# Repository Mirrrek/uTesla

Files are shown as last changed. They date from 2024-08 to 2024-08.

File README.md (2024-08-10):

# uTesla

uTesla (_microTesla_) is a small in size, but definitely impressive Tesla coil. It's core drive circuitry is inspired by [Tefatronix](https://tefatronix.g6.cz/)'s (a fellow Czech!) SSTC IV. The driver runs on 24V (up to 28V for those feeling adventurous) and is controlled by an ATmega328P microcontroller with an SD card slot.

## Hardware

uTesla consists of three main components:

### The driver board

Schematics for this board are available in the [schematic](https://github.com/Mirrrek/uTesla/tree/main/schematic) folder.

The board is intended to be installed with the components facing down. The other side of the PCB serves as a shield from the electromagnetic radiation produced by the coil.

Additional shielding may be required, such as covering the ATmega328P with copper tape (make sure not to short anything out!) connected to the grounding pads present throughout the board.

### The primary coil

Similarly to Tefatronix's design, a 16 pin ribbon cable connected in a A-24V, 24V-B, A-24V, 24V-B pattern serves as the primary coil.

The primary diameter should be around 2cm larger than the secondary coil.

### The secondary coil

Again, this closely follows Tefatronix's design. The secondary consists of a ~3.5cm diameter PVC pipe with around 500 turns of 0.1mm enameled copper wire wound around it.

The resonance can be maximized using tuning capacitors, so the secondary coil doesn't have to match exactly.

## Software

Software for uTesla is a work in progress.

## Expansion

For simple changes (e.g. adding an LCD screen with some buttons) the board has an IO header with 10 pins available.

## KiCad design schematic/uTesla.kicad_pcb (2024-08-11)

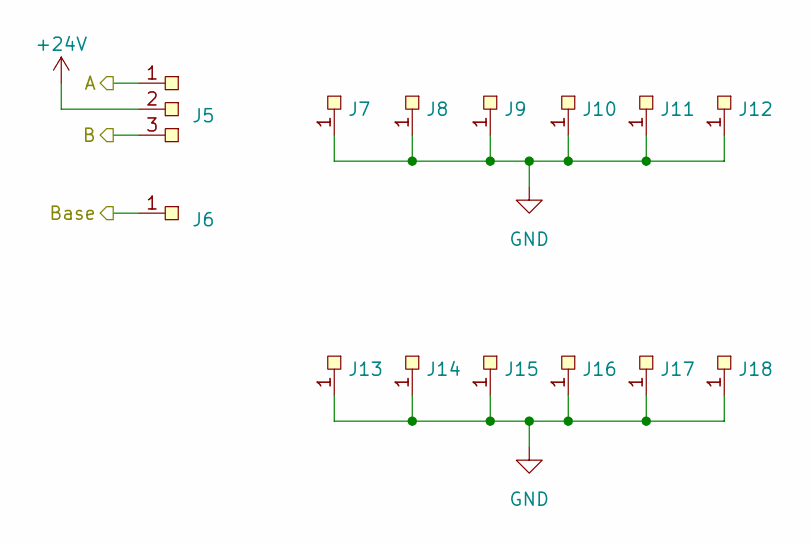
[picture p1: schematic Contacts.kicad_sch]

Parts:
J5: SolderPad-3pin
J6, J7, J8, J9, J10, J11, J12, J13, J14, J15, J16, J17, J18: SolderPad-1pin

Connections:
+24V: J5.2; also elsewhere on the board
/Contacts/A: J5.1; also elsewhere on the board
/Contacts/B: J5.3; also elsewhere on the board
/Contacts/Base: J6.1; also elsewhere on the board
GND: J7.1, J8.1, J9.1, J10.1, J11.1, J12.1, J13.1, J14.1, J15.1, J16.1, J17.1, J18.1; also elsewhere on the board

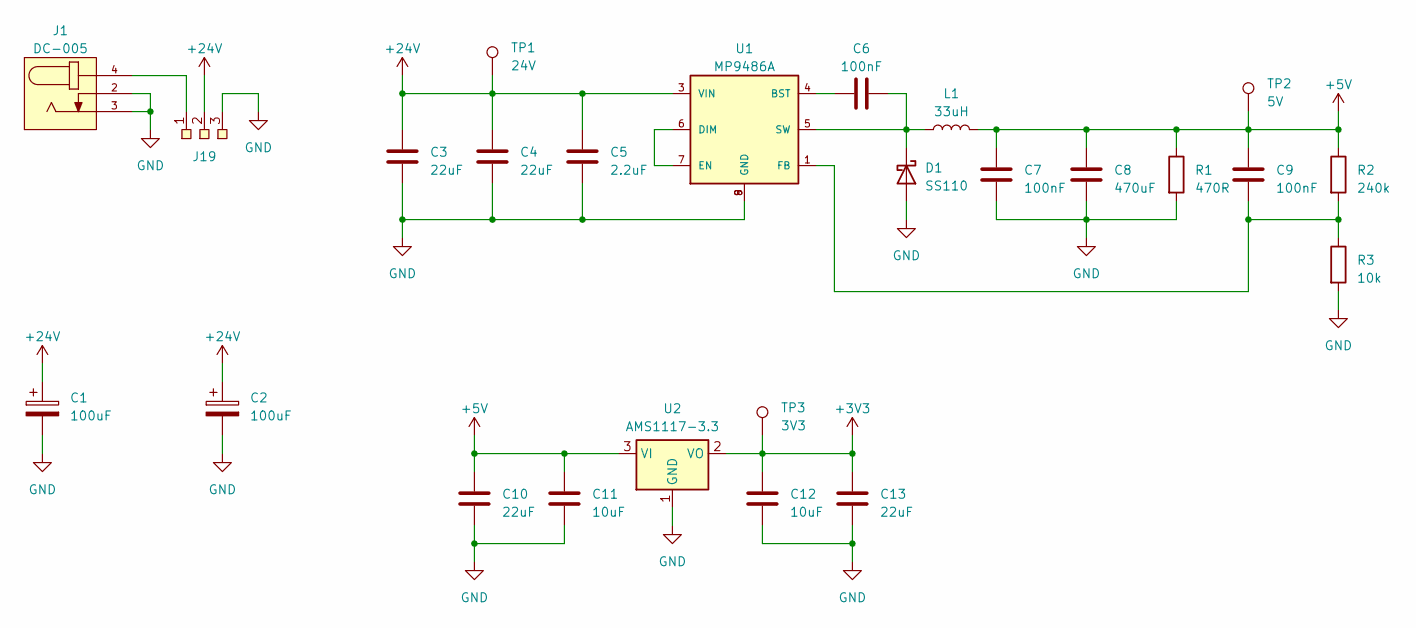
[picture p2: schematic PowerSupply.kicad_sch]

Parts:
C1, C2: 100uF; CP_Radial_D8.0mm_P3.80mm
C3, C4, C10, C13: 22uF; C_0603_1608Metric
C5: 2.2uF; C_0603_1608Metric
C6, C7, C9: 100nF; C_0603_1608Metric
C8: 470uF; C_0603_1608Metric
C11, C12: 10uF; C_0603_1608Metric
D1: SS110; D_SMA
J1: DC-005; NINIGI_DC-005
J19: SolderPad-3pin
L1: 33uH; L_Toroid_Vertical_L26.7mm_W14.0mm_P10.16mm_Pulse_D
R1: 470R; R_0603_1608Metric
R2: 240k; R_0603_1608Metric
R3: 10k; R_0603_1608Metric
TP1: 24V; TestPoint_Pad_D2.0mm
TP2: 5V; TestPoint_Pad_D2.0mm
TP3: 3V3; TestPoint_Pad_D2.0mm
U1: MP9486A; SOIC-8EP
U2: AMS1117-3.3; SOT-223-3_TabPin2

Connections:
+3V3: C12.1, C13.1, TP3.1, U2.2 (VO); also elsewhere on the board
+5V: C7.1, C8.1, C9.1, C10.1, C11.1, L1.2, R1.1, R2.1, TP2.1, U2.3 (VI); also elsewhere on the board
+24V: C1.1, C2.1, C3.1, C4.1, C5.1, J19.2, TP1.1, U1.3 (VIN); also elsewhere on the board
GND: C1.2, C2.2, C3.2, C4.2, C5.2, C7.2, C8.2, C10.2, C11.2, C12.2, C13.2, D1.2 (A), J1.2, J1.3, J19.3, R1.2, R3.2, U1.8 (GND), U1.9 (GND), U2.1 (GND); also elsewhere on the board
unnamed: C6.2, D1.1 (K), L1.1, U1.5 (SW)
unnamed: J1.4, J19.1
unnamed: C6.1, U1.4 (BST)
unnamed: U1.6 (DIM), U1.7 (EN)
unnamed: C9.2, R2.2, R3.1, U1.1 (FB)

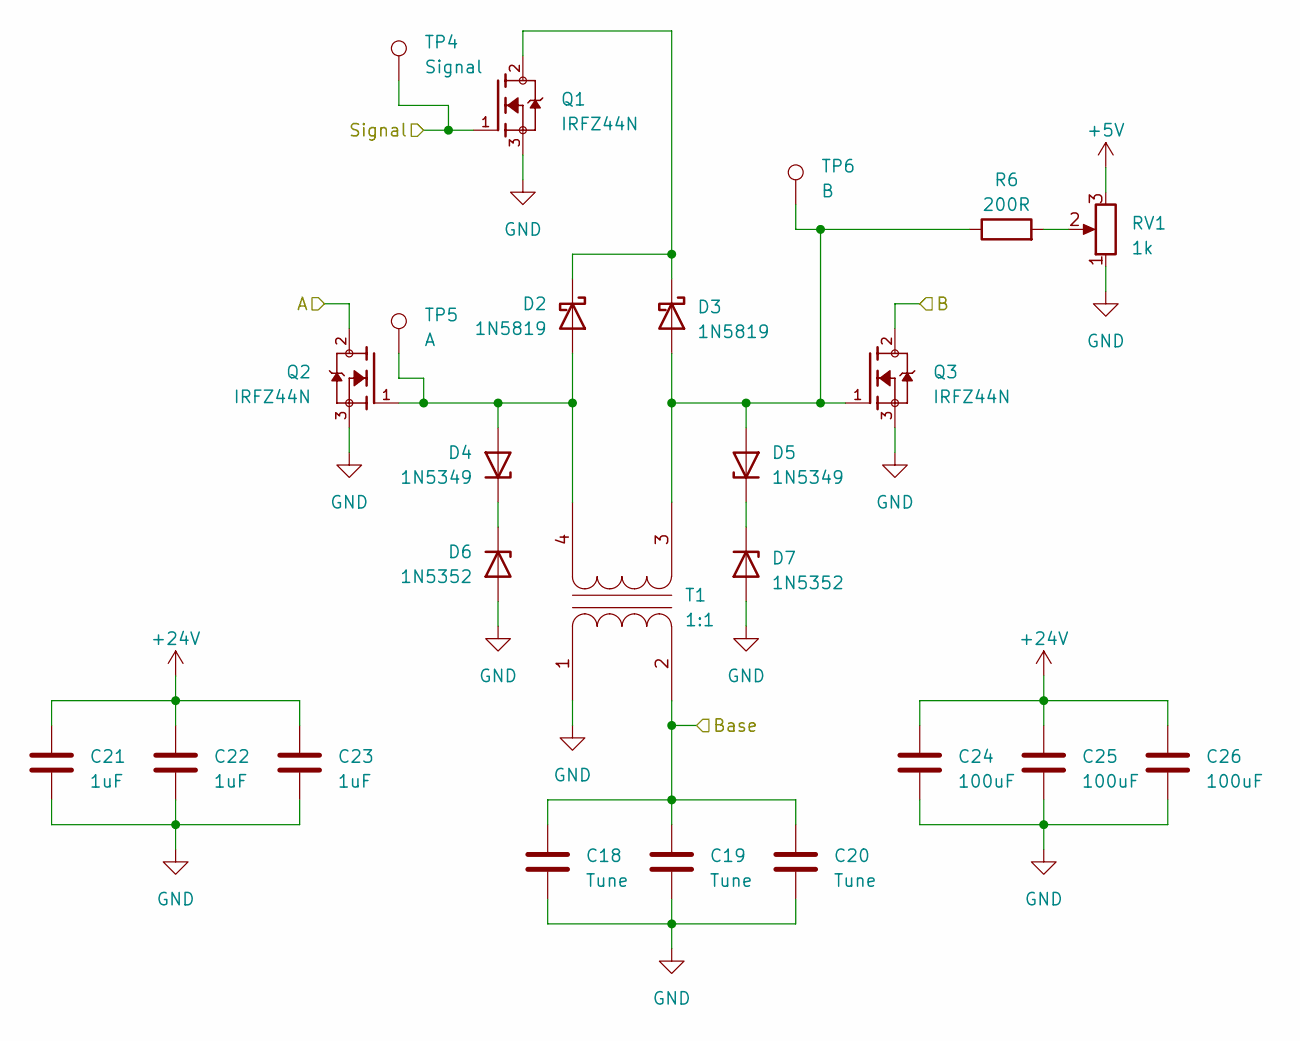
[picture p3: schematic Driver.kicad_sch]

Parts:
C18, C19, C20: Tune; C_0603_1608Metric
C21, C22, C23: 1uF; C_0603_1608Metric
C24, C25, C26: 100uF; CP_Radial_D8.0mm_P3.80mm
D2, D3: 1N5819; D_DO-41_SOD81_P10.16mm_Horizontal
D4, D5: 1N5349; D_DO-41_SOD81_P10.16mm_Horizontal
D6, D7: 1N5352; D_DO-41_SOD81_P10.16mm_Horizontal
Q1, Q2, Q3: IRFZ44N; TO254P1016X419X2286-3; PARTREV 09/21/10
R6: 200R; R_0603_1608Metric
RV1: 1k; Potentiometer_Runtron_RM-065_Vertical
T1: 1:1; Transformer_Toroid_Horizontal_D9.0mm_Amidon-T30
TP4: Signal; TestPoint_Pad_D2.0mm
TP5: A; TestPoint_Pad_D2.0mm
TP6: B; TestPoint_Pad_D2.0mm

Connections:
+5V: RV1.3; also elsewhere on the board
+24V: C21.1, C22.1, C23.1, C24.1, C25.1, C26.1; also elsewhere on the board
/Contacts/A: Q2.2; also elsewhere on the board
/Contacts/B: Q3.2; also elsewhere on the board
/Contacts/Base: C18.1, C19.1, C20.1, T1.2 (AB); also elsewhere on the board
/Driver/Signal: Q1.1, TP4.1; also elsewhere on the board
GND: C18.2, C19.2, C20.2, C21.2, C22.2, C23.2, C24.2, C25.2, C26.2, D6.2 (A), D7.2 (A), Q1.3, Q2.3, Q3.3, RV1.1, T1.1 (AA); also elsewhere on the board
unnamed: D2.2 (A), D4.2 (A), Q2.1, T1.4 (SB), TP5.1
unnamed: D2.1 (K), D3.1 (K), Q1.2
unnamed: D3.2 (A), D5.2 (A), Q3.1, R6.1, T1.3 (SA), TP6.1
unnamed: D4.1 (K), D6.1 (K)
unnamed: D5.1 (K), D7.1 (K)
unnamed: R6.2, RV1.2

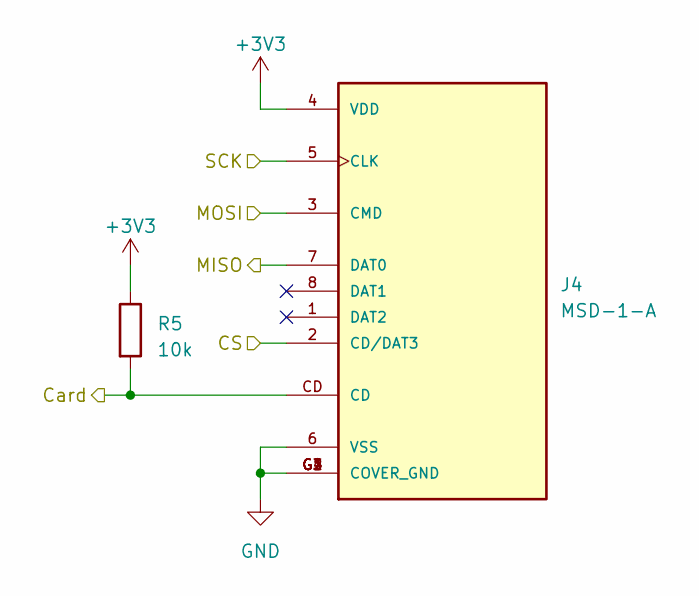
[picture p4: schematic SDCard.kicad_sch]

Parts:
J4: MSD-1-A; CUI_MSD-1-A; PARTREV 1.0
R5: 10k; R_0603_1608Metric

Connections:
+3V3: J4.4 (VDD), R5.1; also elsewhere on the board
/Microcontroller/CS: J4.2 (CD/DAT3); also elsewhere on the board
/Microcontroller/Card: J4.CD, R5.2; also elsewhere on the board
/Microcontroller/MISO: J4.7 (DAT0); also elsewhere on the board
/Microcontroller/MOSI: J4.3 (CMD); also elsewhere on the board
/Microcontroller/SCK: J4.5 (CLK); also elsewhere on the board
GND: J4.6 (VSS), J4.G1 (COVER_GND), J4.G2 (COVER_GND), J4.G3 (COVER_GND), J4.G4 (COVER_GND); also elsewhere on the board

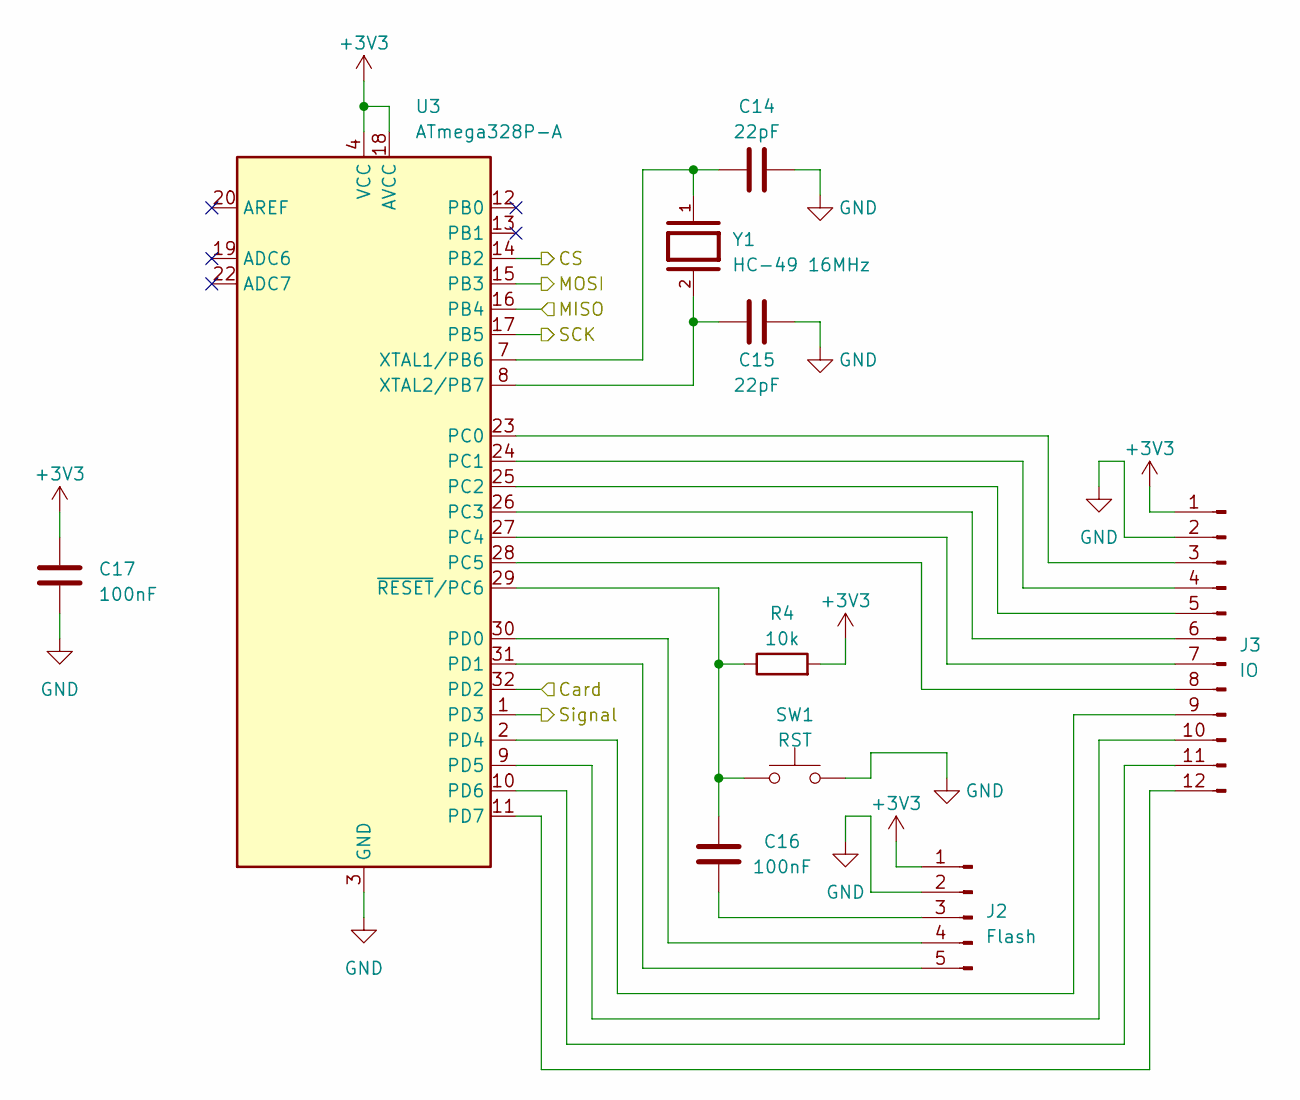
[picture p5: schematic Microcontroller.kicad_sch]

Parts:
C14, C15: 22pF; C_0603_1608Metric
C16, C17: 100nF; C_0603_1608Metric
J2: Flash; PinHeader_1x05_P2.54mm_Vertical
J3: IO; PinHeader_1x12_P2.54mm_Vertical
R4: 10k; R_0603_1608Metric
SW1: RST; SW_PUSH_6mm
U3: ATmega328P-A; TQFP-32_7x7mm_P0.8mm
Y1: HC-49 16MHz; XTAL_HC49P488W43L1150T466H350; PARTREV 1.0

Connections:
+3V3: C17.1, J2.1, J3.1, R4.2, U3.4 (VCC), U3.6 (VCC), U3.18 (AVCC); also elsewhere on the board
/Driver/Signal: U3.1 (PD3); also elsewhere on the board
/Microcontroller/CS: U3.14 (PB2); also elsewhere on the board
/Microcontroller/Card: U3.32 (PD2); also elsewhere on the board
/Microcontroller/MISO: U3.16 (PB4); also elsewhere on the board
/Microcontroller/MOSI: U3.15 (PB3); also elsewhere on the board
/Microcontroller/SCK: U3.17 (PB5); also elsewhere on the board
GND: C14.2, C15.2, C17.2, J2.2, J3.2, SW1.2, U3.3 (GND), U3.5 (GND), U3.21 (GND); also elsewhere on the board
unnamed: C16.1, J2.3
unnamed: J2.4, U3.30 (PD0)
unnamed: J2.5, U3.31 (PD1)
unnamed: J3.3, U3.23 (PC0)
unnamed: J3.4, U3.24 (PC1)
unnamed: J3.5, U3.25 (PC2)
unnamed: J3.6, U3.26 (PC3)
unnamed: J3.7, U3.27 (PC4)
unnamed: J3.8, U3.28 (PC5)
unnamed: J3.9, U3.2 (PD4)
unnamed: J3.10, U3.9 (PD5)
unnamed: J3.11, U3.10 (PD6)
unnamed: J3.12, U3.11 (PD7)
unnamed: C14.1, U3.7 (XTAL1/PB6), Y1.1
unnamed: C15.1, U3.8 (XTAL2/PB7), Y1.2
unnamed: C16.2, R4.1, SW1.1, U3.29 (~RESET/PC6)

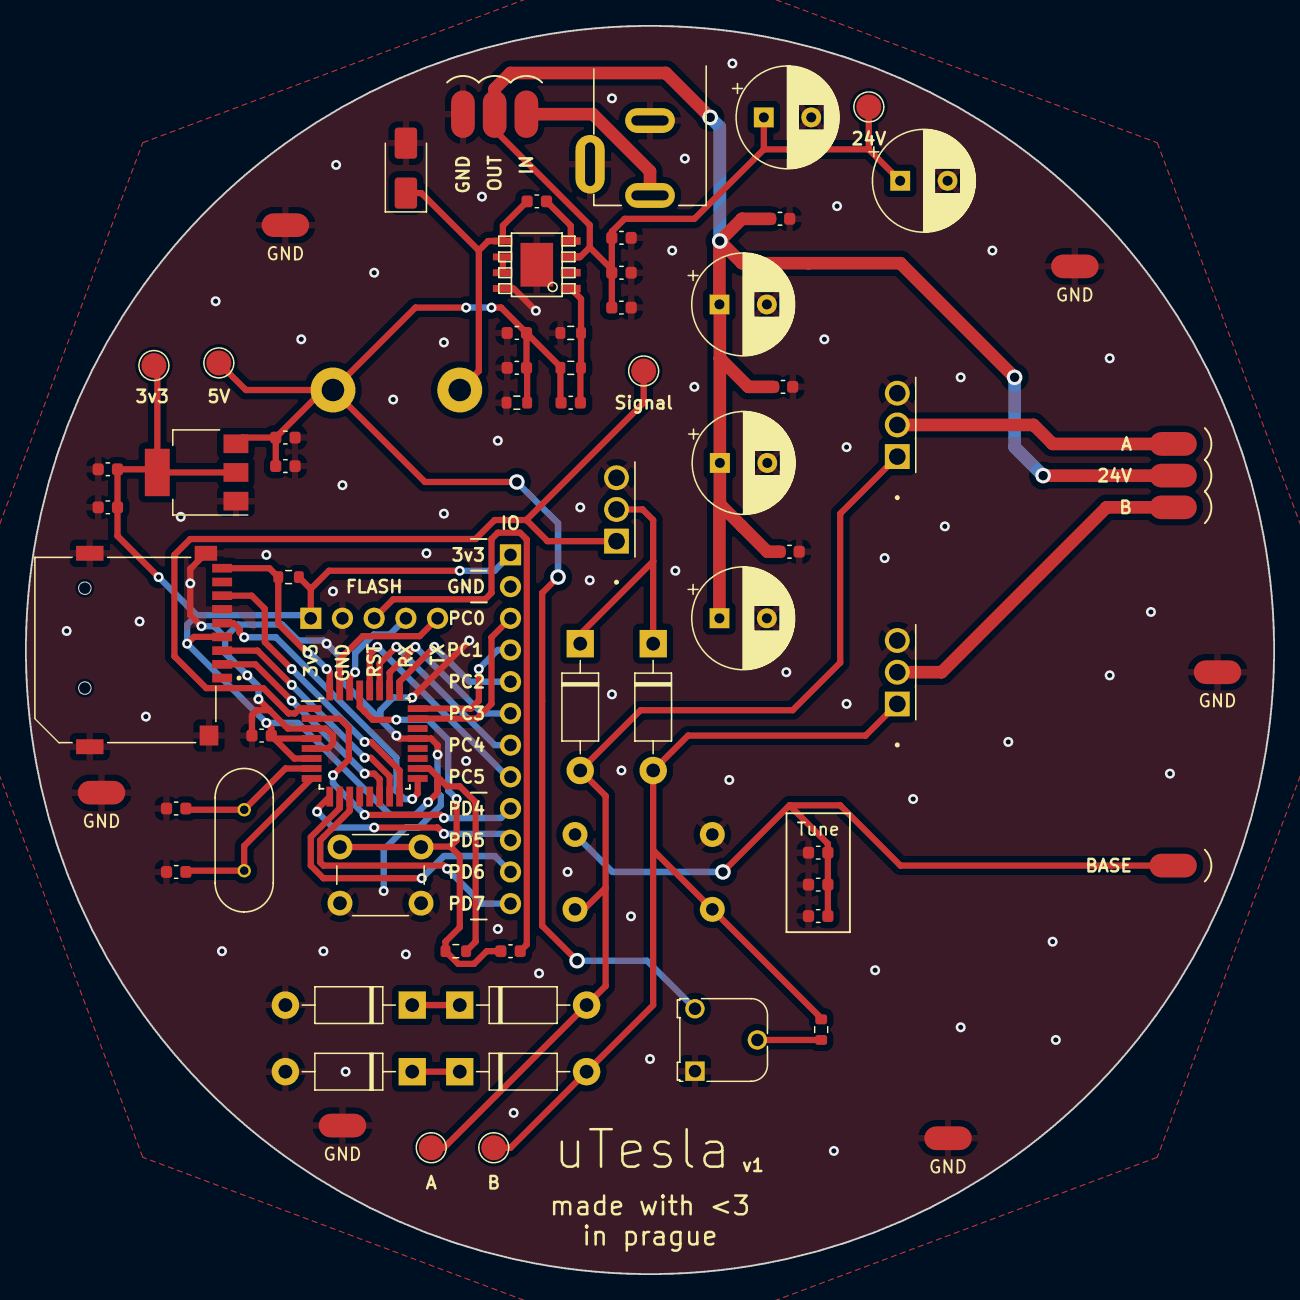
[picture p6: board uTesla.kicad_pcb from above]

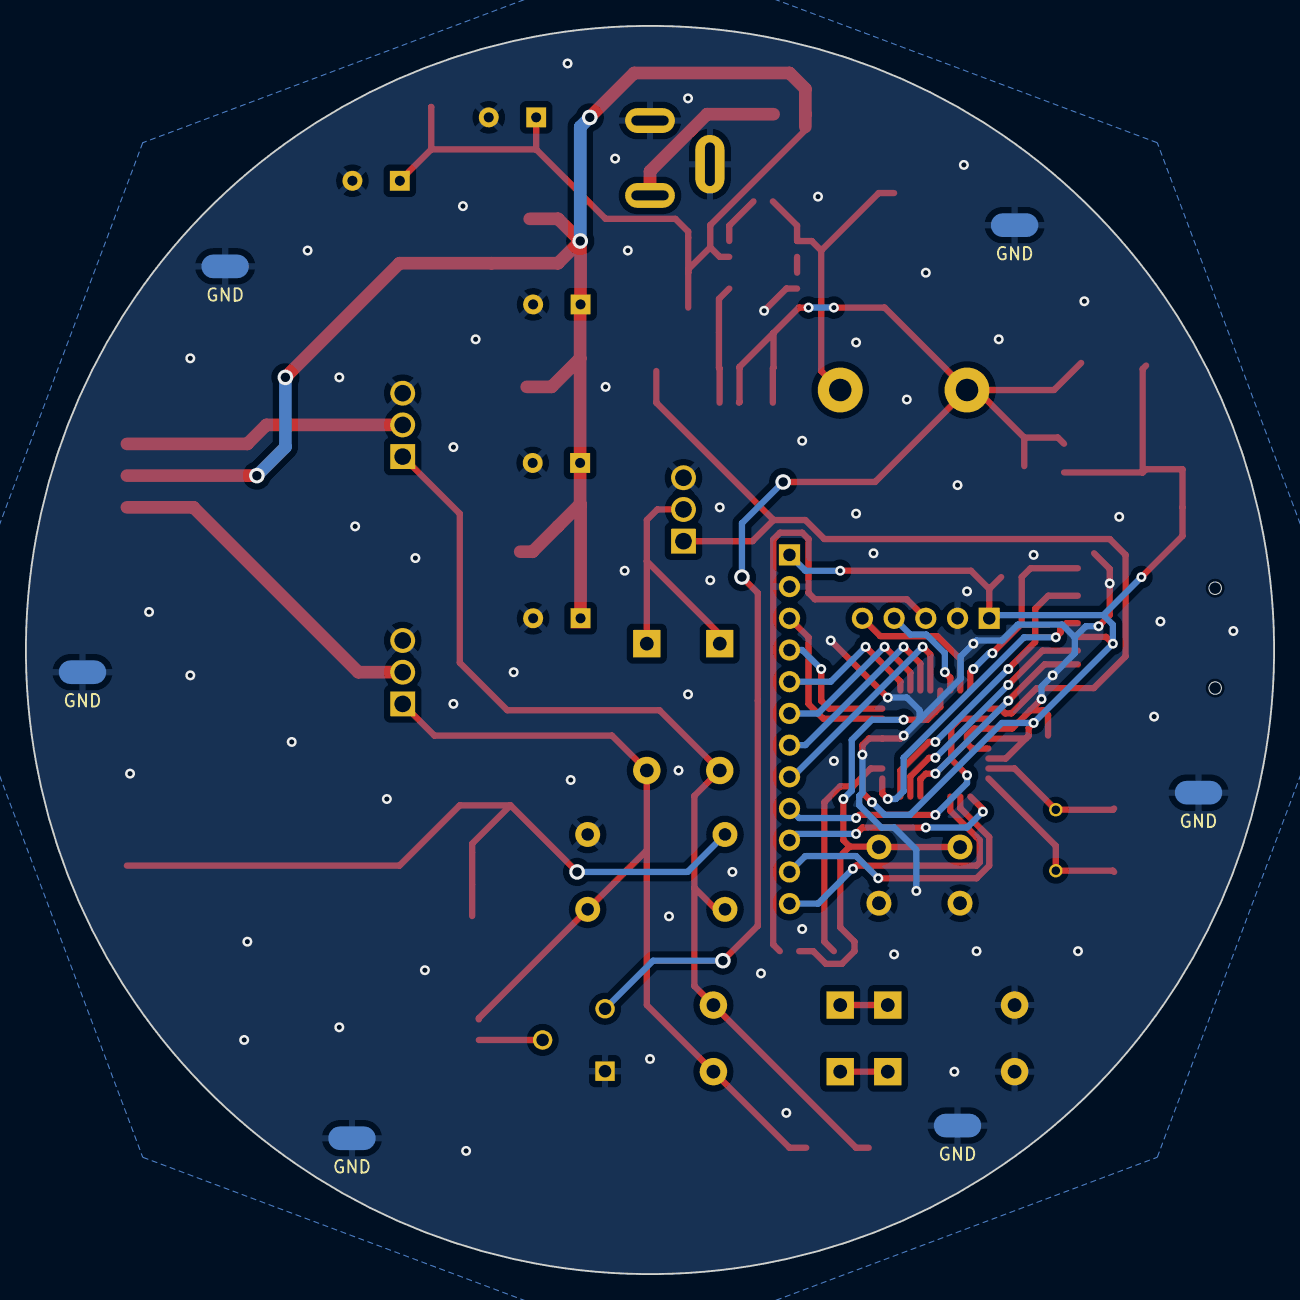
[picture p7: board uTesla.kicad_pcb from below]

Board: 2 copper layers, 100.0 x 100.0 mm, 75 parts (6 on the bottom side), 40 nets.

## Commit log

2024-08-09 Initialize development environment
    [uTesla.kicad_pcb, uTesla.kicad_sch]
2024-08-09 Make high level schematic
    [Contacts.kicad_sch, Driver.kicad_sch, Microcontroller.kicad_sch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]
2024-08-09 Create power supply schematic
    [PowerSupply.kicad_sch]
2024-08-10 Create microcontroller schematic
    [Microcontroller.kicad_sch]
2024-08-10 Create SD card schematic
    [Microcontroller.kicad_sch, SDCard.kicad_sch, uTesla.kicad_sch]
2024-08-10 Create driver schematic
    [Contacts.kicad_sch, Driver.kicad_sch, uTesla.kicad_sch]
2024-08-10 Create connector schematic
    [Contacts.kicad_sch]
2024-08-10 Add test points to driver signals
    [Driver.kicad_sch, Microcontroller.kicad_sch, PowerSupply.kicad_sch]
2024-08-10 Decrease input decoupling capacitance
    [PowerSupply.kicad_sch]
2024-08-10 Assign footprints
    [Driver.kicad_sch, Microcontroller.kicad_sch, PowerSupply.kicad_sch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]
2024-08-10 Fix driver transformer footprint
    [Driver.kicad_sch, PowerSupply.kicad_sch]
2024-08-10 Add grounding solder pads
    [Contacts.kicad_sch]
2024-08-10 Design PCB
    [Driver.kicad_sch, uTesla.kicad_pcb]
2024-08-10 Add power switch
    [PowerSupply.kicad_sch]
2024-08-10 Add silkscreen labels
    [uTesla.kicad_pcb]
2024-08-10 Generate gerber files
    [uTesla-B_Cu.gbl, uTesla-B_Mask.gbs, uTesla-B_Paste.gbp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]
2024-08-11 Scale down PCB
    [uTesla.kicad_pcb]
